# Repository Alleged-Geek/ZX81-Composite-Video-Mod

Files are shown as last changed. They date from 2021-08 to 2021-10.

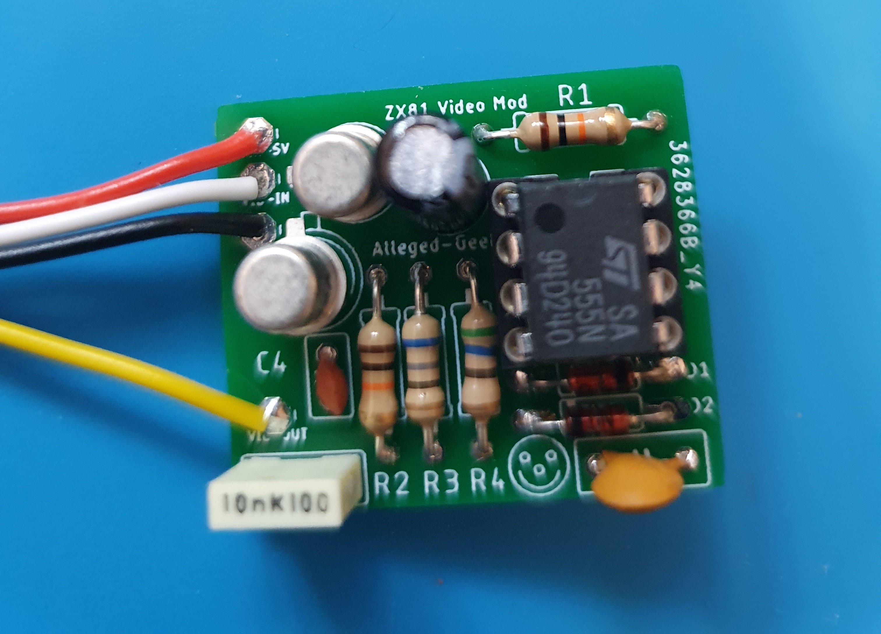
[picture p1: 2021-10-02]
Populated V1 PCB.jpg

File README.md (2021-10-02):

# ZX81-Composite-Video-Mod
Here is my design of the ZX81 composite video mod

In this entry you will find 

Eagle PCB files should you want to modify the circuit in any way

A zipped file containing all the Gerber files which you can simply drag and drop on the JLPCB website (zxmod_2021-08-31.zip)

Images of the PCB layouts and schematic

An image of my populated V1 PCB (the one available for download here has the capacitors C3 and C5 in parallel on the bottom right hand side of the PCB)

Parts List

An excel spreadsheet in pdf format which contains a partslist of the components needed, as well as order codes and prices for Rapidonline.com

I couldn't get a reasonably priced 820pF Ceramic Disc capacitor from Rapid so I placed two capacitors in parallell (C3 and C5) and I suggest you solder a 
470pF and a 330pF in the space for them on the PCB. Alternaatively; if you do get an 820pF Capacitor just solder it into the C3 position.

As the minimum order for a PCB from JLPCB is 5, the order from Rapidonline.com has enough components to populate 5 circuit boards.

For more information, please visit my blog 

alleged-geek.blogspot.com

Alternatively, feel free to ask me any questions about the mod be sending me an email 

alleged_geek@aol.com

I hope that you find this useful

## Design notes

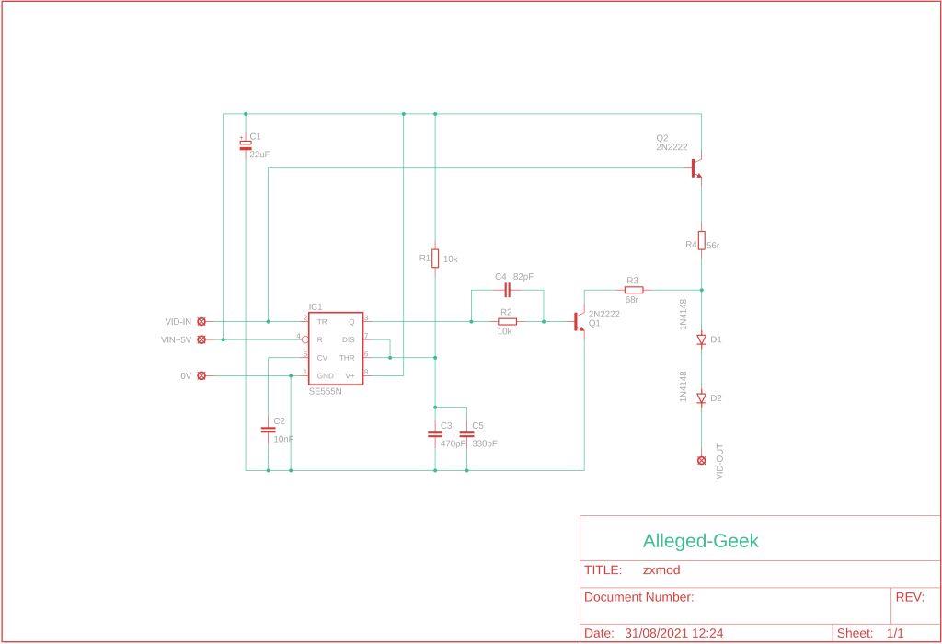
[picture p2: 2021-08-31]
ZX81 Comp Mod-SCH.jpg

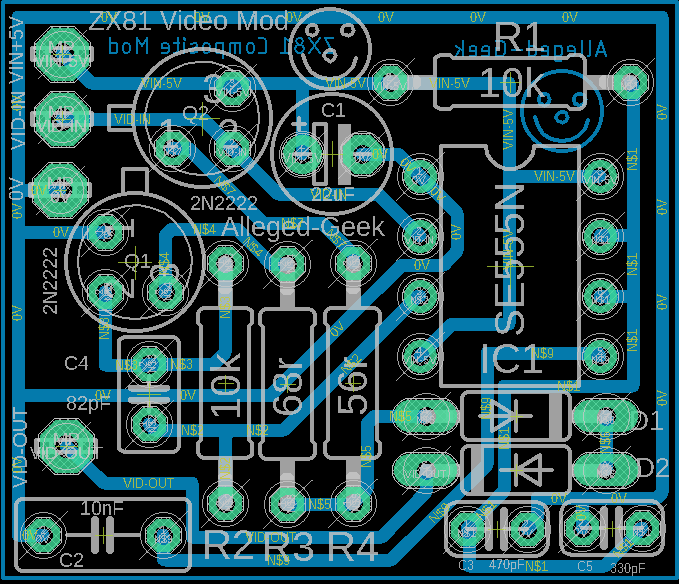
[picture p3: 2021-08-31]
ZX81 Comp Mod-BRD.bmp

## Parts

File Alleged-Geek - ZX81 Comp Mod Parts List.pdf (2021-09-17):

Alleged-Geek ZX81 Composite Video Modification Parts List from www.rapidonline.com
Product Code | Quantity | Product Description | Unit Price | Line Total
81-0256 | 10 | CDIL 2N2222A NPN Transistor General Purpose RF | £0.46 | £4.57
11-0230 | 5 | Forever RB 22U 25V 85Â°C Radial Lead Aluminium Electrolytic Capacitor | £0.04 | £0.21
73-0077 | 10 | Royal Ohm CFR01SJ0103A10 10K 5% 1W Axial Carbon Film Resistor | £0.10 | £0.98
73-0062 | 5 | Royal Ohm CFR01SJ0680A10 68R 5% 1W Axial Carbon Film Resistor | £0.10 | £0.49
73-0114 | 5 | Royal Ohm CFR01SJ0560A10 56R 5% 1W Axial Carbon Film Resistor | £0.10 | £0.49
| | | £0.07
47-3416 | 100 | DC Components 1N4148 Signal Diode 75V 150mA (https://www.rapidonline.com/dc-components-1n4148-signal-diode-75v-150ma-47-3416) | £0.02 | £1.52
11-3406. | 5 | Kemet R82EC2100AA50K 10nf 10% 100V 5mm Polyester Box Capacitor (https://www.rapidonline.com/kemet-r82ec2100aa50k-10nf-10-100v-5mm-polyester-box-capacitor-10-3250) | | £0.34
11-3407. | 10 | Suntan TS170R2A820JSBNA0R 82pF 5% 100V NPO P:2.54mm Radial Ceramic Capacitor | £0.05 | £0.52
11-3433. | 10 | Suntan TS170R2A471JSBNA0R 470pF 5% 100V NPO P:2.54mm Radial Ceramic Capacitor | £0.09 | £0.91
11-3432. | 10 | Suntan TS170R2A331JSBNA0R 330pF 5% 100V NPO P:2.54mm Radial Ceramic Capacitor | £0.10 | £0.95
82-0336 | 5 | Texas Instruments NE555P Bipolar Single Timer | £0.44 | £2.20
Total | £13.18

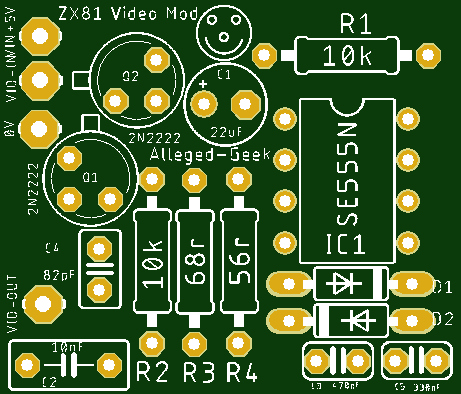
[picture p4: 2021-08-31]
ZX81 Comp Mod Component Side.jpg

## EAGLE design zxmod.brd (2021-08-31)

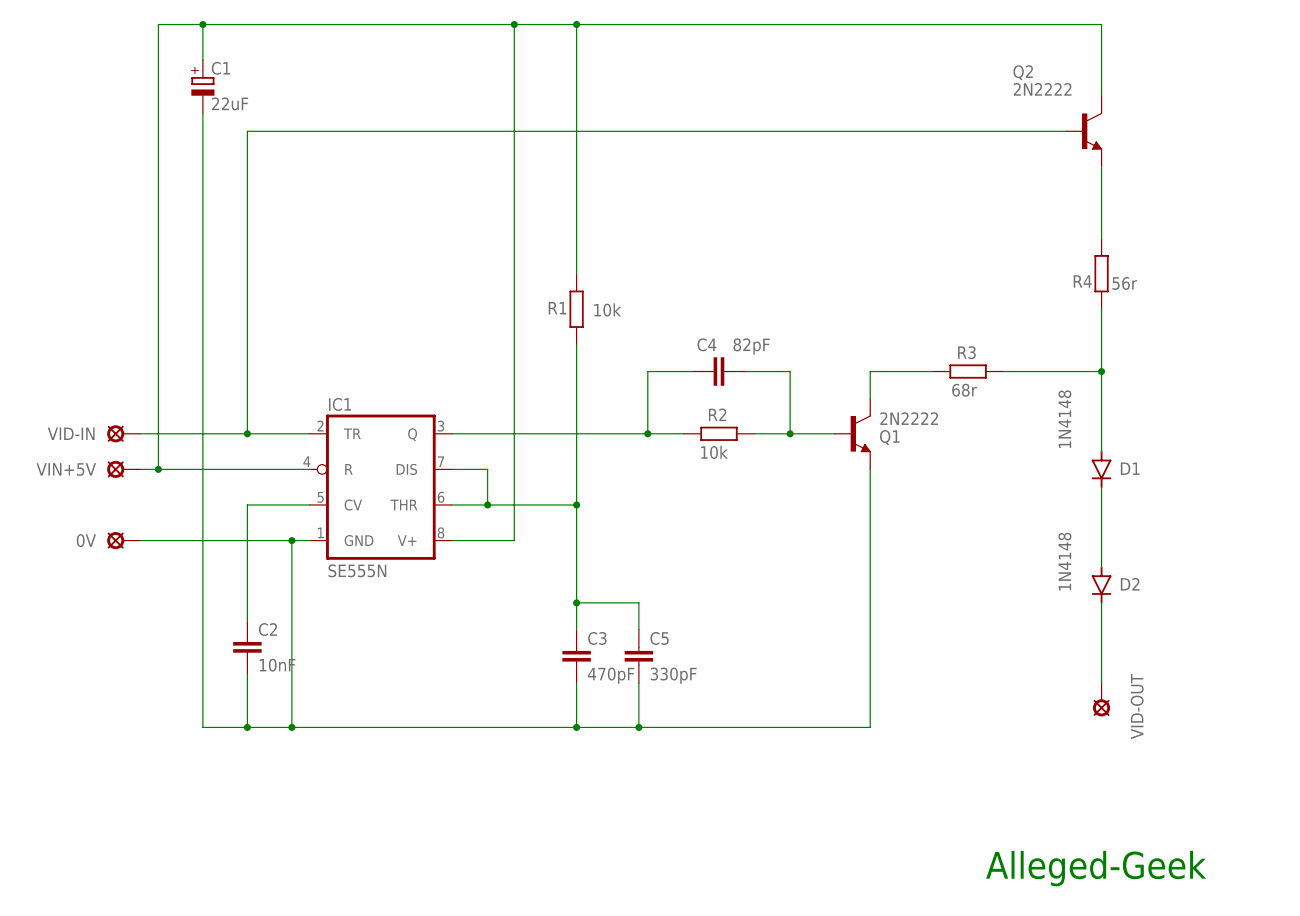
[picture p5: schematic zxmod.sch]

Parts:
0V: LSP10
C1: 22uF; E2,5-5
C2: 10nF; C050-030X075
C3: 470pF; C025-024X044
C4: 82pF; C025-025X050
C5: 330pF; C025-024X044
D1, D2: 1N4148; DO35-7
IC1: SE555N; DIL08
Q1, Q2: 2N2222; TO18
R1, R2: 10k; 0207/10
R3: 68r; 0207/10
R4: 56r; 0207/10
VID-IN: LSP10
VID-OUT: LSP10
VIN+5V: LSP10

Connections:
0V: 0V.MP, C1.-, C2.2, C3.2, C5.2, IC1.1 (GND), Q1.1 (E)
unnamed: C3.1, C5.1, IC1.6 (THR), IC1.7 (DIS), R1.1
unnamed: C4.1, IC1.3 (Q), R2.2
unnamed: C4.2, Q1.2 (B), R2.1
unnamed: Q1.3 (C), R3.2
unnamed: D1.A, R3.1, R4.1
unnamed: D1.C, D2.A
unnamed: Q2.1 (E), R4.2
unnamed: C2.1, IC1.5 (CV)
VID-IN: IC1.2 (TR), Q2.2 (B), VID-IN.MP
VID-OUT: D2.C, VID-OUT.MP
VIN-5V: C1.+, IC1.4 (R), IC1.8 (V+), Q2.3 (C), R1.2, VIN+5V.MP

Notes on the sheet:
Alleged-Geek

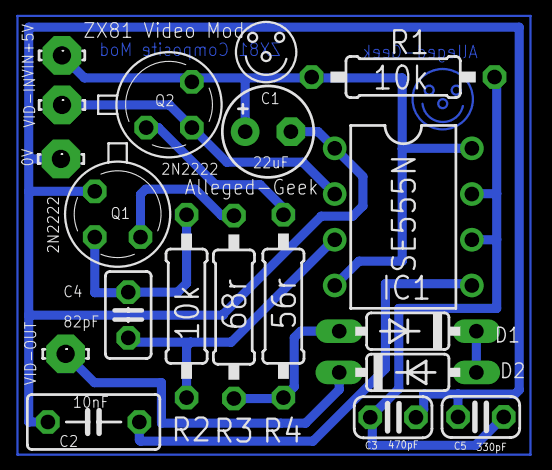
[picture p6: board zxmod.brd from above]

Board: 2 copper layers, 18 parts (0 on the bottom side), 12 nets.

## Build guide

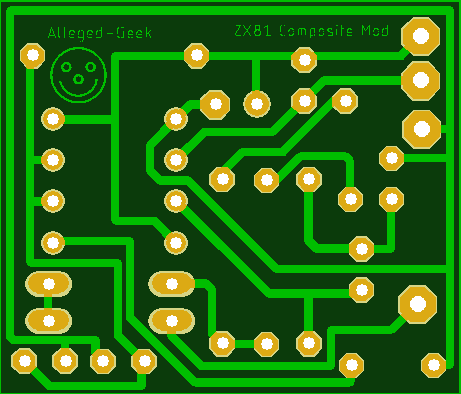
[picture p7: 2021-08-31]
ZX81 Comp Mod Solder Side.jpg
